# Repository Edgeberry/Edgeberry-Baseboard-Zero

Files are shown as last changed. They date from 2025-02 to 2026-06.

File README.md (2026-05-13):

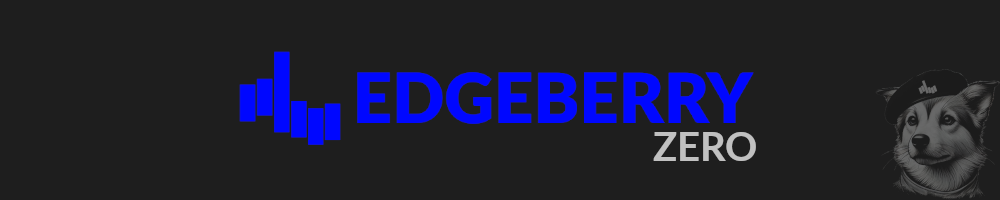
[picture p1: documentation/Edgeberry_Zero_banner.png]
Edgeberry banner


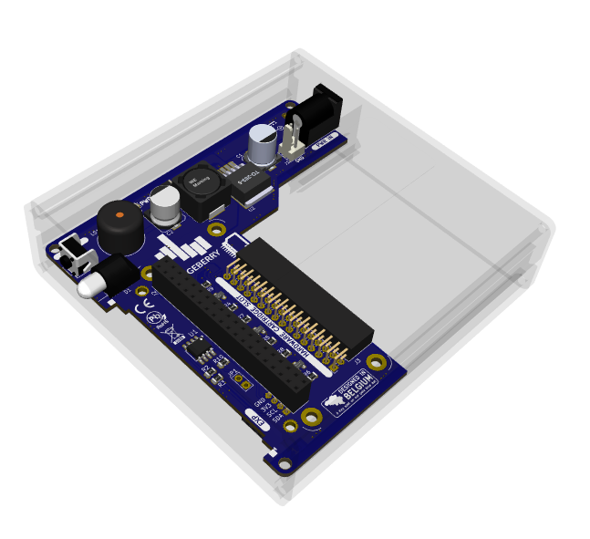
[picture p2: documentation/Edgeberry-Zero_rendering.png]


The **Edgeberry Zero** provides essential additional functionality for deploying the Raspberry Pi Zero as an IoT edge device in a real-world environment.

- **12 to 24VDC input power supply** for reliably powering the device with up to 3A at 5V.
- **Indicators and button** for providing status feedback and device interaction
- **Expansion slot** for application-specific Edgeberry Hardware Cartridges
- **Robust enclosure** for withstanding the environmental challenges of the real world

<br/>
<br clear="right"/>

## Edgeberry Device Software
For using your Edgeberry hardware with the Edgeberry ecosystem (e.g. the Edgeberry Dashboard), you'll need to install the [Edgeberry Device Software](https://github.com/Edgeberry/Edgeberry/). Follow [these installation steps](https://github.com/Edgeberry/Edgeberry?tab=readme-ov-file#installation). If you have different plans with this board, this software is not required for correct operation of any of its hardware components.

## Enclosure
The enclosure, designed in FreeCAD, protects the device from the challenges of the physical world.

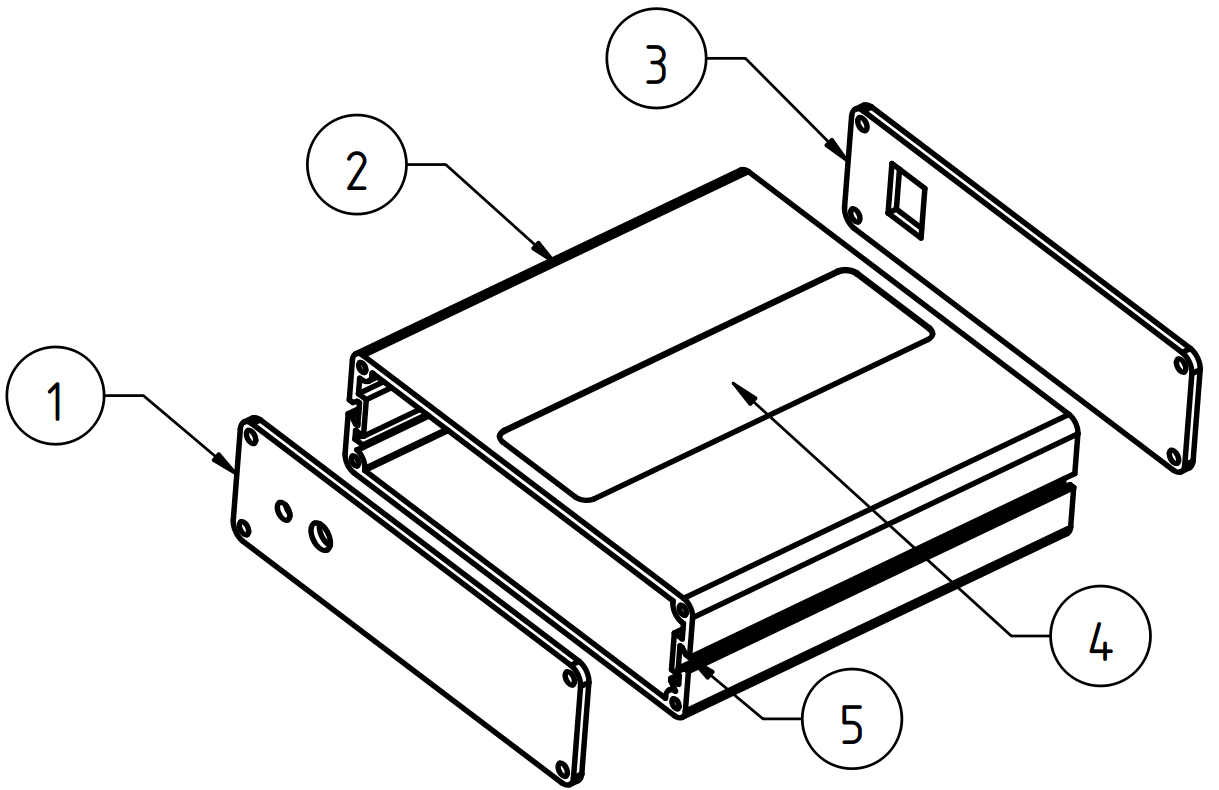
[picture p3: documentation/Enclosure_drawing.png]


1) Faceplate front
2) Enclosure
3) Faceplate back
4) Sticker
5) Mounting groove

<br clear="left"/>

## (re)Writing the EEPROM
>[!important]
>**When you purchased the Edgeberry Hardware, the manufacturer has written the EEPROM**. If you are the manufacturer, or you're hacking your Edgeberry board, then continue with the following steps.

1) Close the `write protection` jumper (JP1) on the Edgeberry Hardware to enable writing the EEPROM
2) Download and build the [Raspberry Pi Hat eeprom utils](https://github.com/raspberrypi/hats) on your device 
3) Make the EEPROM file from the eeprom_settings.txt using `eepmake` <br> e.g. `$ ./eepmake eeprom_settings.txt edgeberry.eep`
4) Flash the EEPROM using `eepflash.sh` <br> e.g. `$ sudo ./eepflash -w -t=24c256 -f=edgeberry.eep`
5) Now `reboot` the device and check the device tree for your hat's settings <br> e.g. `$ cat /proc/device-tree/hat/vendor`)

## License & Collaboration
**Copyright© 2025 Sanne 'SpuQ' Santens**. This project is released under the [**CERN OHL-W**](./LICENSE.txt) license. The [Rules & Guidelines](https://github.com/Edgeberry/.github/blob/main/brand/Edgeberry_Trademark_Rules_and_Guidelines.md) apply to the usage of the Edgeberry™ brand.

### Collaboration

If you'd like to contribute to this project, please follow these guidelines:
1. Fork the repository and create your branch from `main`.
2. Make your changes and ensure they adhere to the project's design style and conventions.
3. Test your changes thoroughly.
4. Ensure your commits are descriptive and well-documented.
5. Open a pull request, describing the changes you've made and the problem or feature they address.

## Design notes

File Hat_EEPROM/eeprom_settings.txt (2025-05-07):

########################################################################
# 	Edgeberry HAT - EEPROM settings
# 	by Sanne 'SpuQ' Santens
#
#	IMPORTANT:	On the Edgeberry Base Board, close the jumper (JP1)
#			to write the EEPROM! Otherwise the device is in
#			read-only mode, but the flash tool indicates successful
#			writing to the EEPROM!
# 	Usage:
#		1) Make sure the jumper (JP1) on the Edgeberry Base Board is closed
#		2) Run this file through eepmake tool
# 		3) Use eepflash tool to write to attached HAT ID EEPROM
#		4) Check the content of the EEPROM using eepdump
#
#	Edits:
#	12/01/2025	vendor		"Edgeberry"
#			product		"Edgeberry Zero"
#			back_power	2 (Edgeberry's power supply can deliver up to 3A)
#			product_id	0x0002 (second Edgeberry product)
#			product_ver	0x0108 (first byte is major number, second byte is minor number)
#			set gpio 5 output (buzzer)
#			set gpio 6 input (button)
#			set gpio 26 output (LED green)
#			set gpio 19 output (LED red)
#			product_uuid 	left at zero to let eepmake auto-generate an RFC4122 compliant UUID
#			gpio_drive, gpio_slew, gpio_hysteresis removed due to error during making eeprom file
#
# Resources:
#	https://forums.raspberrypi.com/viewtopic.php?t=108134
#	https://github.com/raspberrypi/hats/tree/master/eepromutils
#
########################################################################

########################################################################
# Vendor info

# 128 bit UUID. If left at zero eepmake tool will auto-generate
# RFC 4122 compliant UUID
product_uuid 00000000-0000-0000-0000-000000000000

# 16 bit product id
product_id 0x0002

# 16 bit product version
product_ver 0x0108

# ASCII vendor string  (max 255 characters)
vendor "Edgeberry"

# ASCII product string (max 255 characters)
product "Edgeberry Zero"

########################################################################
# GPIO bank settings, set to nonzero to change from the default.
# NOTE these setting can only be set per BANK, uncommenting any of
# these will force the bank to use the custom setting.

# If board back-powers Pi via 5V GPIO header pins:
# 0 = board does not back-power
# 1 = board back-powers and can supply the Pi with a minimum of 1.3A
# 2 = board back-powers and can supply the Pi with a minimum of 2A
# 3 = reserved
# If back_power=2 then USB high current mode will be automatically 
# enabled on the Pi
back_power 2

########################################################################
# GPIO pins, uncomment for GPIOs used on board
# Options for FUNCTION: INPUT, OUTPUT, ALT0-ALT5
# Options for PULL: DEFAULT, UP, DOWN, NONE
# NB GPIO0 and GPIO1 are reserved for ID EEPROM so cannot be set
#
# Note:  The GPIO map is parsed by the Videocore bootloader prior to ARM boot and not Linux

#         GPIO  FUNCTION  PULL
#         ----  --------  ----
#setgpio  2     INPUT     DEFAULT
#setgpio  3     INPUT     DEFAULT
#setgpio  4     INPUT     DEFAULT
setgpio  5     OUTPUT     DEFAULT
setgpio  6     INPUT     DEFAULT
#setgpio  7     INPUT     DEFAULT
#setgpio  8     INPUT     DEFAULT
#setgpio  9     INPUT     DEFAULT
#setgpio  10    INPUT     DEFAULT
#setgpio  11    INPUT     DEFAULT
#setgpio  12    INPUT     DEFAULT
#setgpio  13    INPUT     DEFAULT
#setgpio  14    INPUT     DEFAULT
#setgpio  15    INPUT     DEFAULT
#setgpio  16    INPUT     DEFAULT
#setgpio  17    INPUT     DEFAULT
#setgpio  18    INPUT     DEFAULT
setgpio  19    OUTPUT     DEFAULT
#setgpio  20    INPUT     DEFAULT
#setgpio  21    INPUT     DEFAULT
#setgpio  22    INPUT     DEFAULT
#setgpio  23    INPUT     DEFAULT
#setgpio  24    INPUT     DEFAULT
#setgpio  25    INPUT     DEFAULT
setgpio  26    OUTPUT     DEFAULT
#setgpio  27    INPUT     DEFAULT

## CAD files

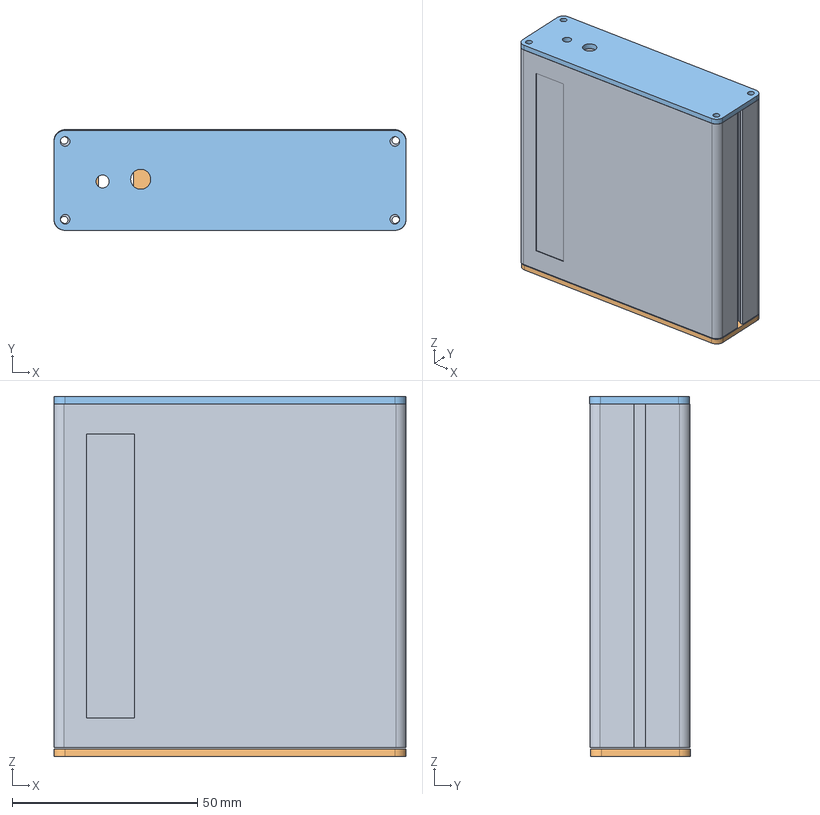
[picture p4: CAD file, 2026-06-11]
Enclosure/Edgeberry-Zero_Enclosure.FCStd
95.0 x 27.2 x 97.2 mm
Edgeberry_Zero_Enclosure
Faceplate_back
Faceplate_front

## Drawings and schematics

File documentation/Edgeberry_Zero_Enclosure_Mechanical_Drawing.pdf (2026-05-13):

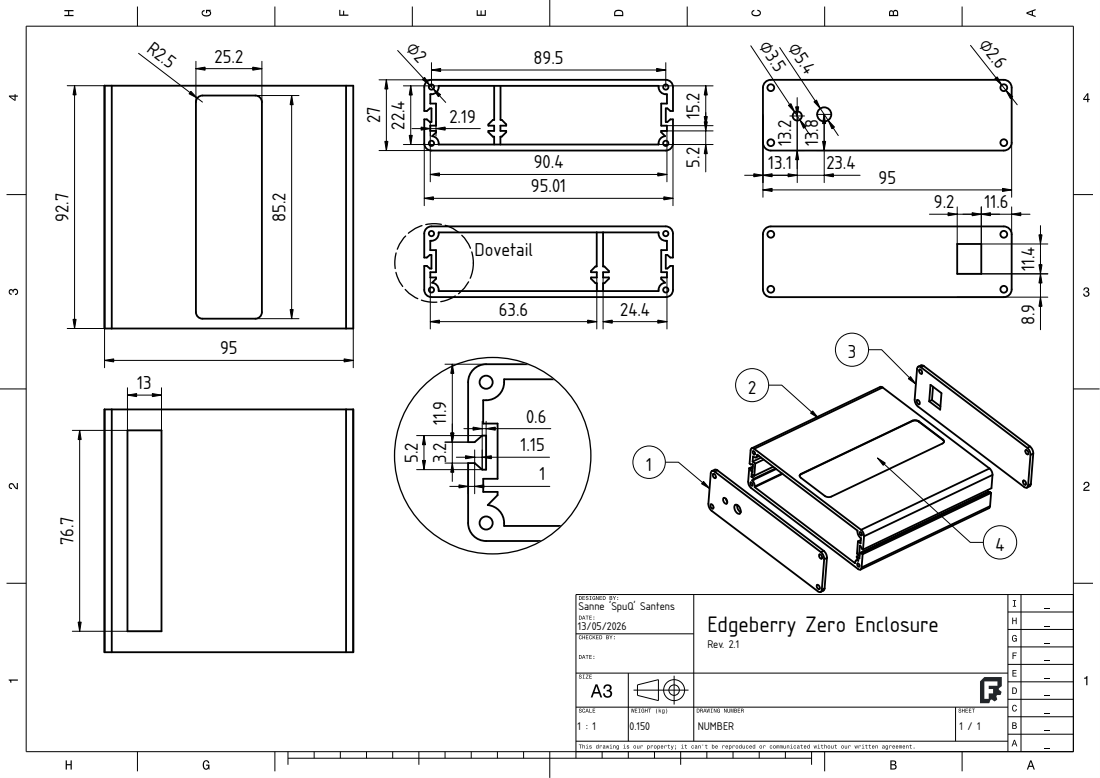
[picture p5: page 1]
NUMBER

Sanne 'SpuQ' Santens

Edgeberry Zero Enclosure
Rev. 2.1

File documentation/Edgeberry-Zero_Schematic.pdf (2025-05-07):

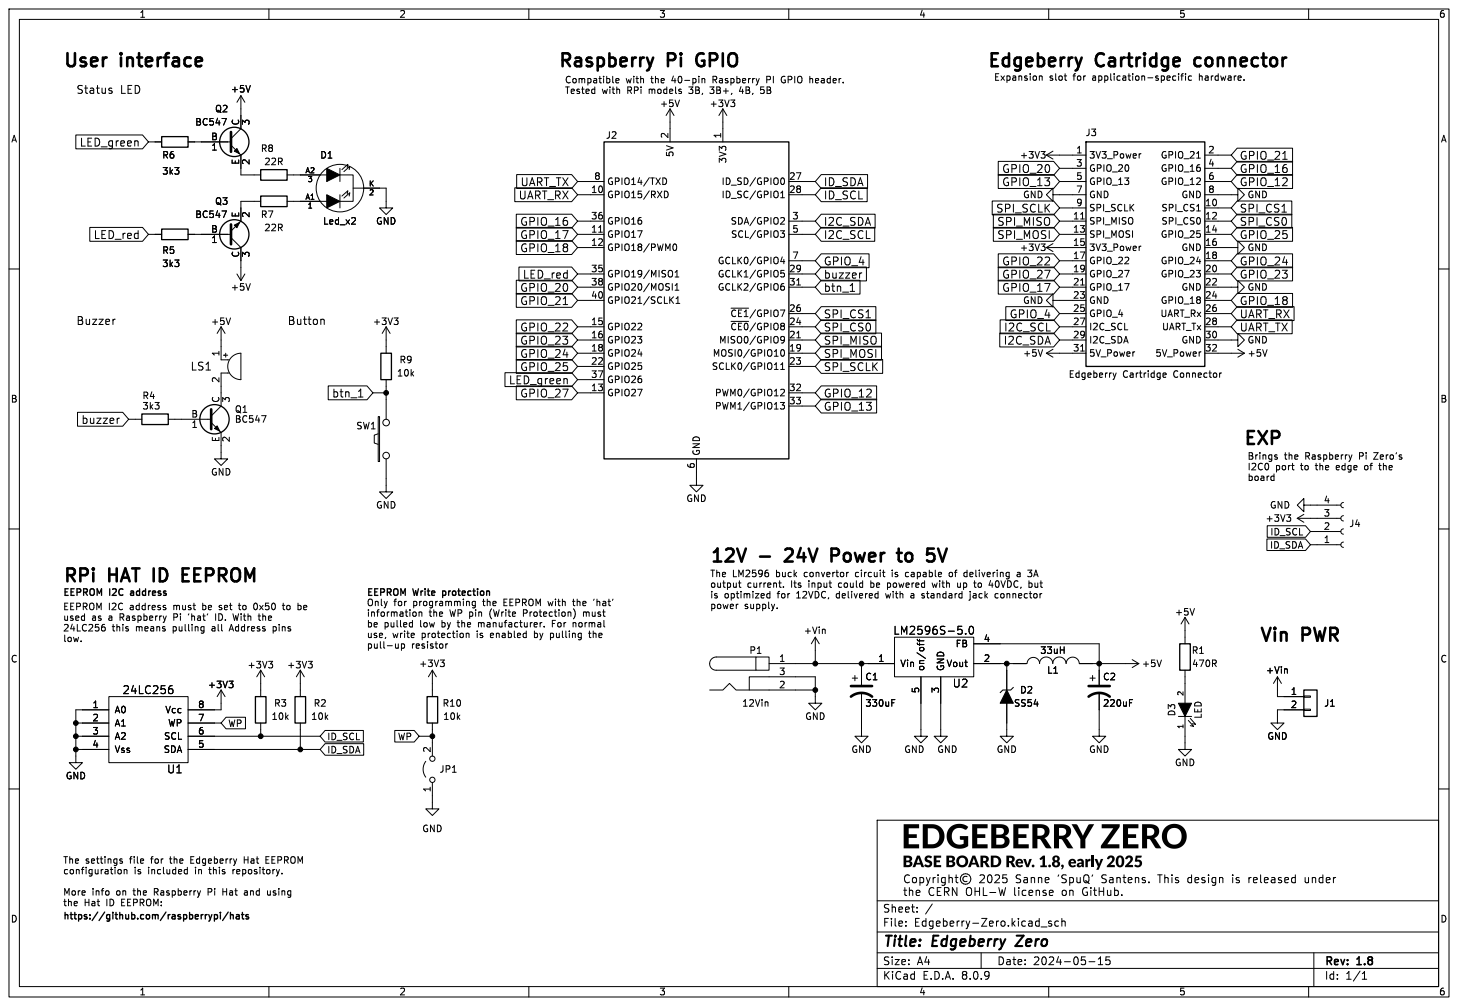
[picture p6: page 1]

LED_red
GPIO_20
GPIO_21
https://github.com/raspberrypi/hats EEPROM I2C address GND
EEPROM I2C address must be set to 0x50 to be

Brings the Raspberry Pi Zero's
I2C0 port to the edge of the

low. RPi HAT ID EEPROM

used as a Raspberry Pi 'hat' ID. With the

þÿCopyright© 2025 Sanne 'SpuQ' Santens. This design is released under
the CERN OHL-W license on GitHub.
File: Edgeberry-Zero.kicad_sch Sheet: /
Id: 1/1 Title: Edgeberry Zero

the Hat ID EEPROM:

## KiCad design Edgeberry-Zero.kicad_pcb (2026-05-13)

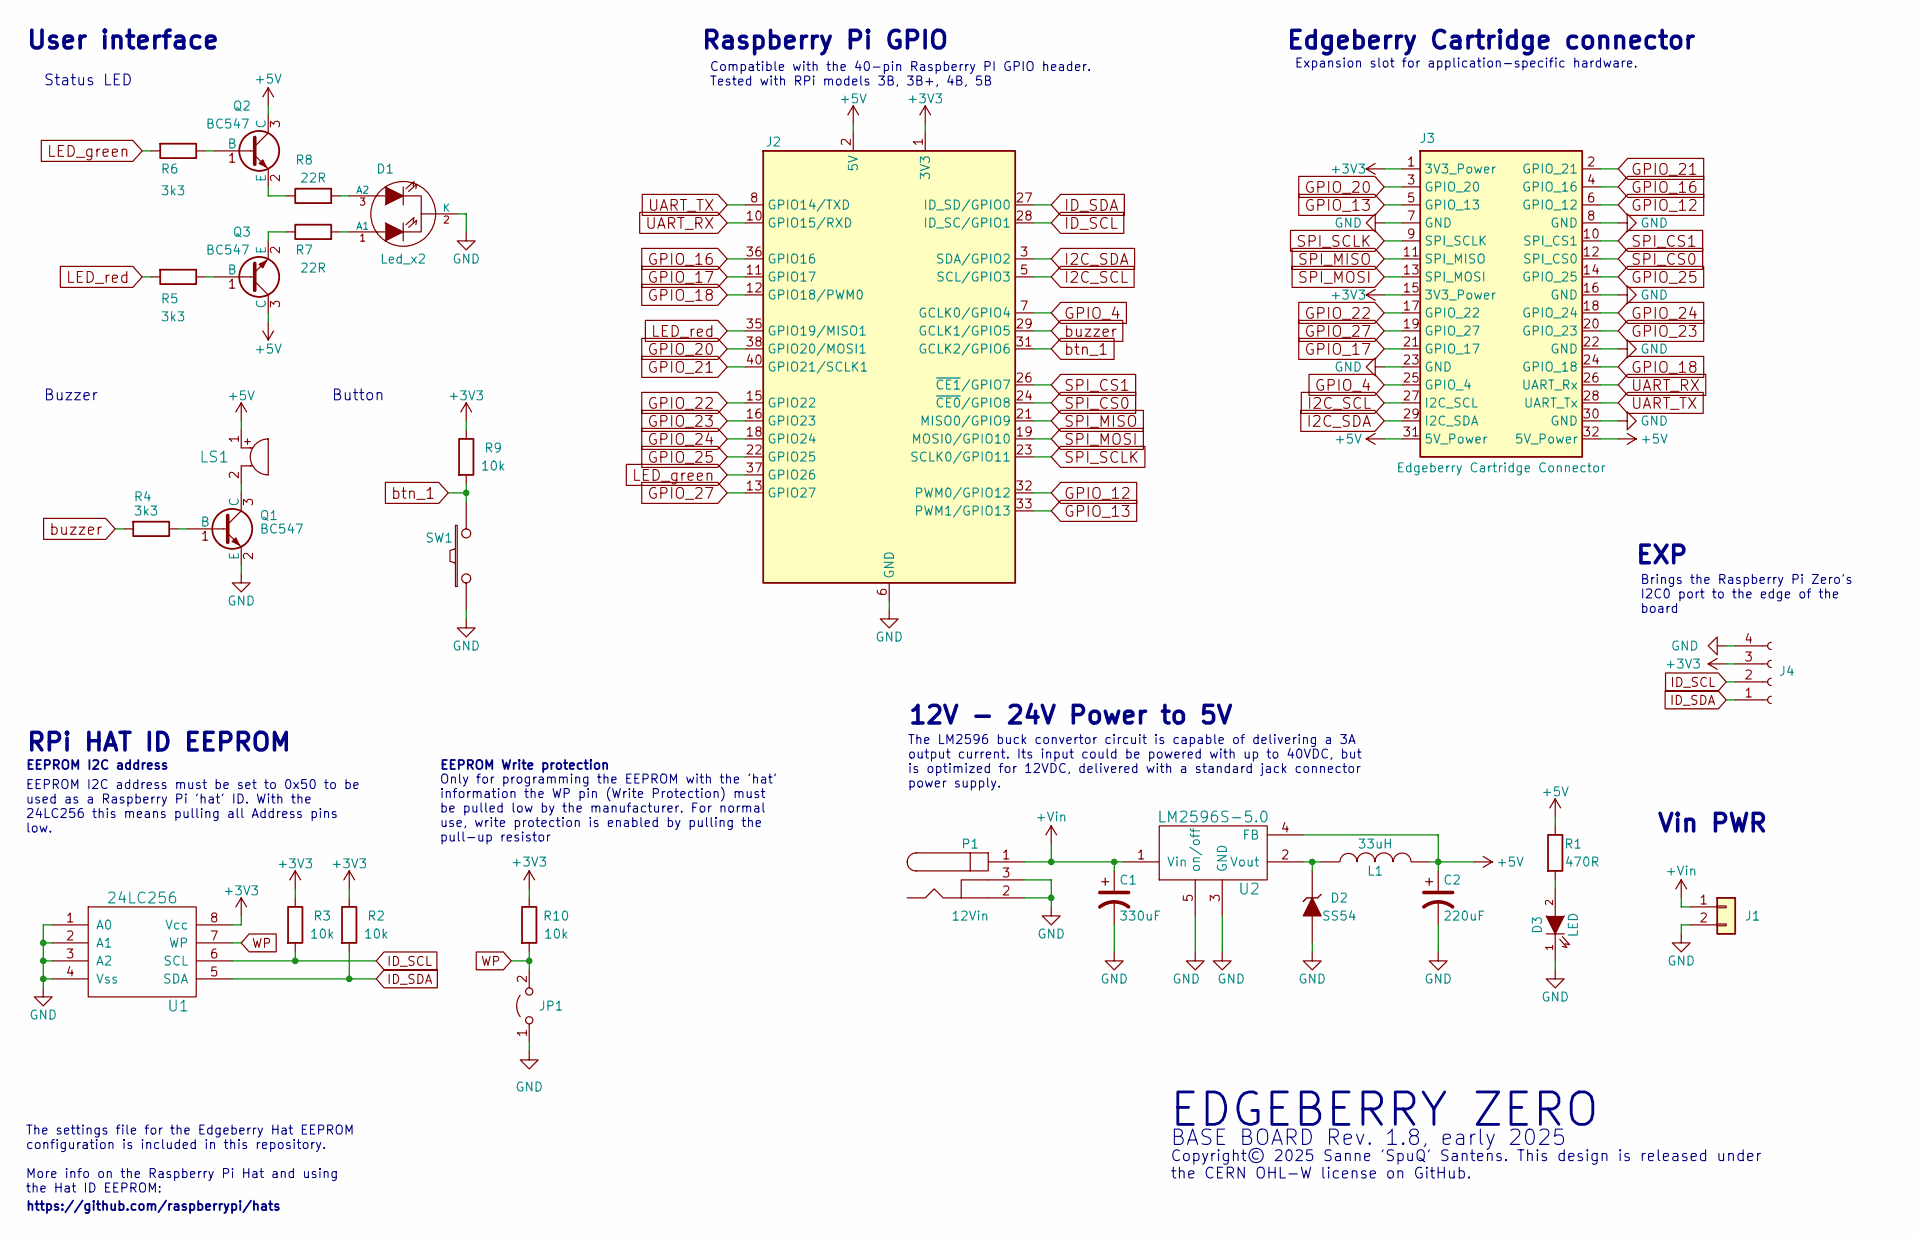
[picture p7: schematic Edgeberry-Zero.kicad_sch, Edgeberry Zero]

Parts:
C1: 330uF; c_elec_8x10
C2: 220uF; c_elec_8x10
D1: Led_x2; bicolor_LED_right_angle
D2: SS54; D_SMA
D3: LED; LED_0805_2012Metric
J1: Molex_KK_1x02_P2.54mm; Molex_KK-254_AE-6410-02A_1x02_P2.54mm_Vertical
J2: Raspberry_Pi_2_3; PinSocket_2x20_P2.54mm_Vertical
J3: Edgeberry Cartridge Connector; PinSocket_2x16_P2.54mm_Horizontal
J4: Conn_01x04_Socket; PinSocket_1x04_P2.00mm_Horizontal
JP1: Jumper_2_Open; PinHeader_1x02_P2.54mm_Vertical
L1: 33uH; SELF-WE-PD-XXL
LS1: Buzzer; Buzzer_12x9.5RM7.6
P1: 12Vin; BarrelJack_Horizontal
Q1, Q2, Q3: BC547; SOT-23
R1: 470R; R_0805_2012Metric
R2, R3, R9, R10: 10k; R_0805_2012Metric
R4, R5, R6: 3k3; R_0805_2012Metric
R7, R8: 22R; R_0805_2012Metric
SW1: SW_PUSH; tactile_switch_vertical
U1: 24LC256; SOIC_8
U2: LM2596S-5.0; TO-263-5_TabPin3

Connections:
+3V3: J2.1 (3V3), J2.17 (3V3), J3.1 (3V3_Power), J3.15 (3V3_Power), J4.3, R2.1, R3.1, R9.1, R10.1, U1.8 (Vcc)
+5V: C2.1, J2.2 (5V), J2.4 (5V), J3.31 (5V_Power), J3.32 (5V_Power), L1.2, LS1.1, Q2.3 (C), Q3.3 (C), R1.1, U2.4 (FB)
+Vin: C1.1, J1.1, P1.1, U2.1 (Vin)
GND: C1.2, C2.2, D1.2 (K), D2.2 (A), D3.1 (K), J1.2, J2.6 (GND), J2.9 (GND), J2.14 (GND), J2.20 (GND), J2.25 (GND), J2.30 (GND), J2.34 (GND), J2.39 (GND), J3.7 (GND), J3.8 (GND), J3.16 (GND), J3.22 (GND), J3.23 (GND), J3.30 (GND), J4.4, JP1.1 (A), P1.2, P1.3, Q1.2 (E), SW1.1, U1.1 (A0), U1.2 (A1), U1.3 (A2), U1.4 (Vss), U2.3 (GND), U2.5 (on/off)
GPIO_4: J2.7 (GCLK0/GPIO4), J3.25 (GPIO_4)
GPIO_12: J2.32 (PWM0/GPIO12), J3.6 (GPIO_12)
GPIO_13: J2.33 (PWM1/GPIO13), J3.5 (GPIO_13)
GPIO_16: J2.36 (GPIO16), J3.4 (GPIO_16)
GPIO_17: J2.11 (GPIO17), J3.21 (GPIO_17)
GPIO_18: J2.12 (GPIO18/PWM0), J3.24 (GPIO_18)
GPIO_20: J2.38 (GPIO20/MOSI1), J3.3 (GPIO_20)
GPIO_21: J2.40 (GPIO21/SCLK1), J3.2 (GPIO_21)
GPIO_22: J2.15 (GPIO22), J3.17 (GPIO_22)
GPIO_23: J2.16 (GPIO23), J3.20 (GPIO_23)
GPIO_24: J2.18 (GPIO24), J3.18 (GPIO_24)
GPIO_25: J2.22 (GPIO25), J3.14 (GPIO_25)
GPIO_27: J2.13 (GPIO27), J3.19 (GPIO_27)
I2C_SCL: J2.5 (SCL/GPIO3), J3.27 (I2C_SCL)
I2C_SDA: J2.3 (SDA/GPIO2), J3.29 (I2C_SDA)
ID_SCL: J2.28 (ID_SC/GPIO1), J4.2, R3.2, U1.6 (SCL)
ID_SDA: J2.27 (ID_SD/GPIO0), J4.1, R2.2, U1.5 (SDA)
LED_green: J2.37 (GPIO26), R6.2
LED_red: J2.35 (GPIO19/MISO1), R5.2
unnamed: D1.1 (A1), R7.2
unnamed: D1.3 (A2), R8.2
unnamed: D2.1 (K), L1.1, U2.2 (Vout)
unnamed: D3.2 (A), R1.2
unnamed: Q1.1 (B), R4.1
unnamed: LS1.2, Q1.3 (C)
unnamed: Q2.1 (B), R6.1
unnamed: Q2.2 (E), R8.1
unnamed: Q3.1 (B), R5.1
unnamed: Q3.2 (E), R7.1
SPI_CS0: J2.24 (~CE0/GPIO8), J3.12 (SPI_CS0)
SPI_CS1: J2.26 (~CE1/GPIO7), J3.10 (SPI_CS1)
SPI_MISO: J2.21 (MISO0/GPIO9), J3.11 (SPI_MISO)
SPI_MOSI: J2.19 (MOSI0/GPIO10), J3.13 (SPI_MOSI)
SPI_SCLK: J2.23 (SCLK0/GPIO11), J3.9 (SPI_SCLK)
UART_RX: J2.10 (GPIO15/RXD), J3.26 (UART_Rx)
UART_TX: J2.8 (GPIO14/TXD), J3.28 (UART_Tx)
WP: JP1.2 (B), R10.2, U1.7 (WP)
btn_1: J2.31 (GCLK2/GPIO6), R9.2, SW1.2
buzzer: J2.29 (GCLK1/GPIO5), R4.2

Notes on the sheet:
Copyright© 2025 Sanne 'SpuQ' Santens. This design is released under the CERN OHL-W license on GitHub.
Button
BASE BOARD Rev. 1.8, early 2025
EEPROM I2C address must be set to 0x50 to be used as a Raspberry Pi 'hat' ID. With the 24LC256 this means pulling all Address pins low.
User interface
12V - 24V Power to 5V
EEPROM Write protection
Raspberry Pi GPIO
Vin PWR
Brings the Raspberry Pi Zero's I2C0 port to the edge of the board
RPi HAT ID EEPROM
https://github.com/raspberrypi/hats
The settings file for the Edgeberry Hat EEPROM configuration is included in this repository. More info on the Raspberry Pi Hat and using the Hat ID EEPROM:
The LM2596 buck convertor circuit is capable of delivering a 3A output current. Its input could be powered with up to 40VDC, but is optimized for 12VDC, delivered with a standard jack connector power supply.
EXP
Only for programming the EEPROM with the 'hat' information the WP pin (Write Protection) must be pulled low by the manufacturer. For normal use, write protection is enabled by pulling the pull-up resistor
Buzzer
Status LED
EDGEBERRY ZERO
Expansion slot for application-specific hardware.
Edgeberry Cartridge connector
EEPROM I2C address
Compatible with the 40-pin Raspberry PI GPIO header. Tested with RPi models 3B, 3B+, 4B, 5B

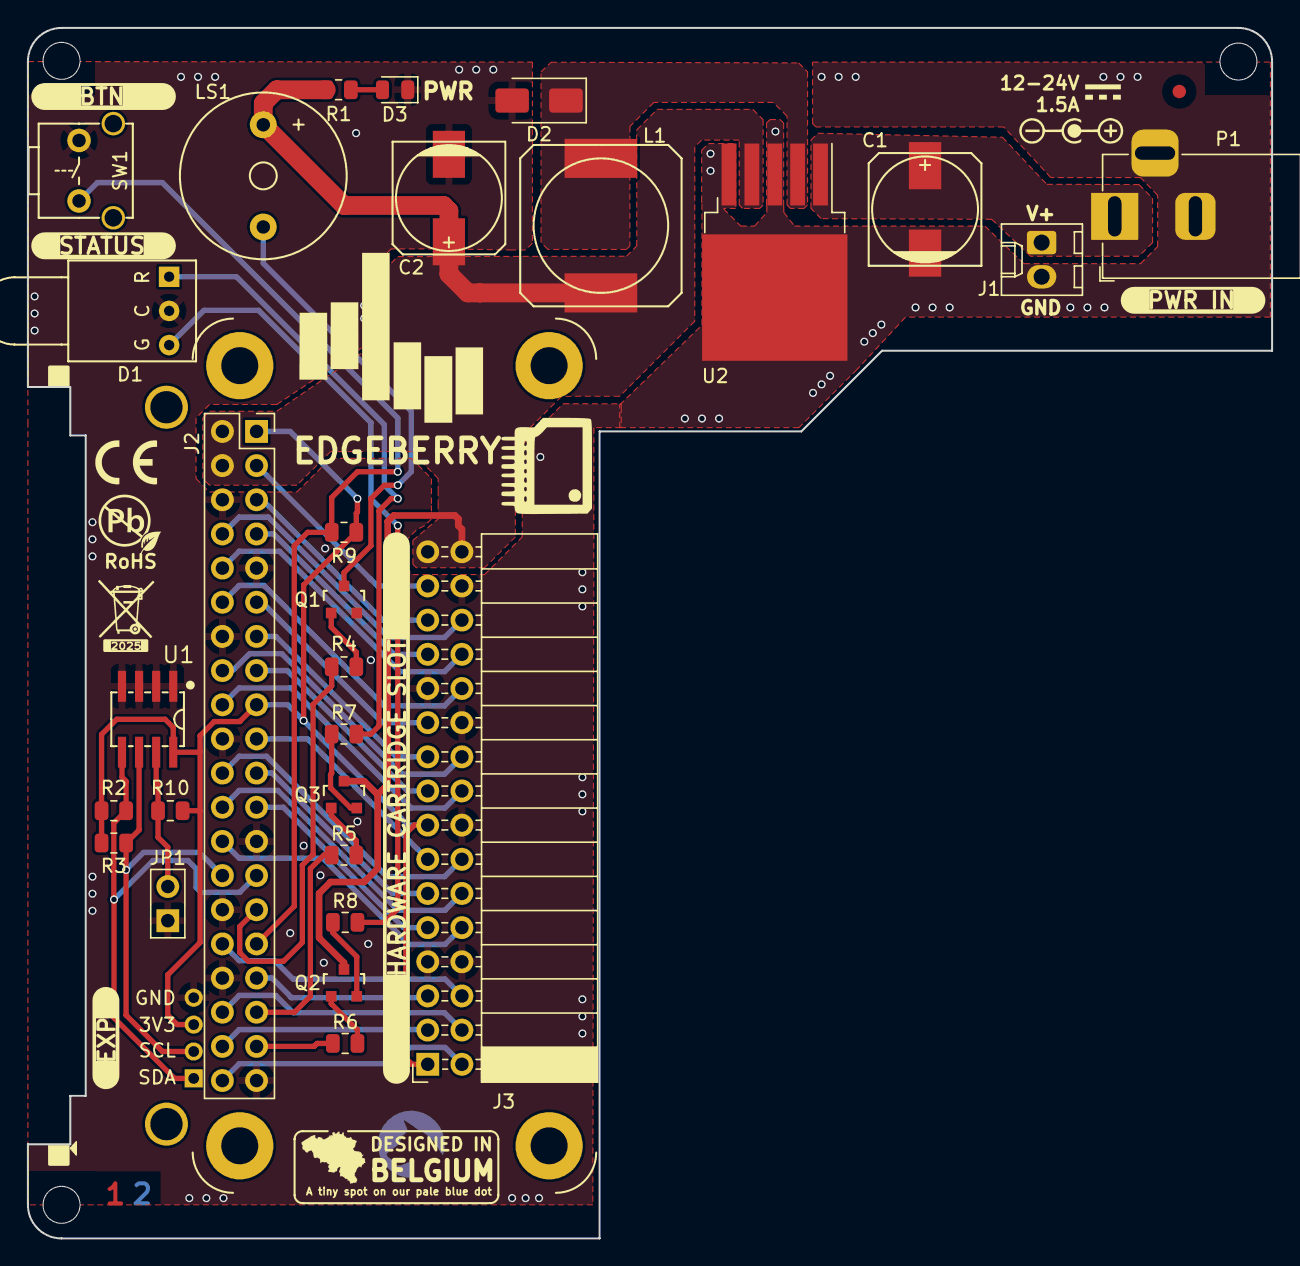
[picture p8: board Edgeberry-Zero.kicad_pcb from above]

Board: 2 copper layers, 92.5 x 90.0 mm, 29 parts (1 on the bottom side), 43 nets.

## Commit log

2025-02-12 Edgeberry Zero concept
    [Edgeberry-Zero.kicad_pcb, Edgeberry-Zero.kicad_sch, Edgeberry-Zero_Enclosure.FCStd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]
2025-02-12 Even smaller
    [Edgeberry-Zero.kicad_pcb]
2025-02-12 Component arrangement + Mechanical dimensions
    [Edgeberry-Zero.kicad_pcb, Edgeberry-Zero_Enclosure.FCStd]
2025-02-13 Enclosure updates
    [Edgeberry-Zero.kicad_pcb, Edgeberry-Zero_Enclosure.FCStd]
2025-02-27 Finished design
    [Edgeberry-Zero.kicad_pcb, Edgeberry-Zero.kicad_sch, Edgeberry-Zero_Enclosure.FCStd]
2025-02-27 Enclosure: logo
    [Edgeberry-Zero_Enclosure.FCStd]
2025-03-20 Documentation: Enclosure mechanical drawing
    [Edgeberry-Zero_Enclosure.FCStd]
2025-03-20 Documentation: Enclosure mechanical drawing pdf format
2025-04-26 Improvements: C2, J4 (ext)
    [Edgeberry-Zero.kicad_pcb, Edgeberry-Zero.kicad_sch, Edgeberry-Zero_Enclosure.FCStd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]
2025-05-07 Rev 1.8
    [Edgeberry-Zero.kicad_pcb, Edgeberry-Zero.kicad_sch]
2025-05-07 Rendering for rev 8.1
    [Edgeberry-Zero.kicad_pcb]
2026-05-08 Enclosure directory
    [Edgeberry-Zero_Enclosure_old.FCStd]
2026-05-08 Enclosure revision
    [Edgeberry-Zero_Enclosure.FCStd]
2026-05-13 Enclosure Rev 2.1
    [Edgeberry-Zero_Enclosure.FCStd, Edgeberry-Zero_Enclosure_old.FCStd]
2026-05-13 Updated enclosure implementation
    [Edgeberry-Zero.kicad_pcb]
2026-05-13 Enclosure: Logo sticker template
2026-05-13 Enclosure: Mechanical Drawing
    [Edgeberry-Zero_Enclosure.FCStd]
2026-05-13 ReadMe: Enclosure section concept
2026-05-13 Docs: Enclosure drawing cleanup
2026-05-13 ReadMe: Enclosure drawing cleanup
2026-05-13 Enclosure: mounting groove doc
    [Edgeberry-Zero_Enclosure.FCStd]
2026-05-13 Organization improvements
    [Edgeberry-Zero_front.kicad_pcb, Edgeberry-Zero_front.kicad_sch]
2026-06-11 Enclosure: Faceplate back improvement
    [Edgeberry-Zero_Enclosure.FCStd]
